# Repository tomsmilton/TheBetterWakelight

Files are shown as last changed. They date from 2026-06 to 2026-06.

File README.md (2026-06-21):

# TheBetterWakelight

Two independent takes on the same idea: an **ESP32-based DMX sunrise
controller for the Neewer PL60C**. The ESP32 plugs into the lamp's 5-pin
DMX port and ramps it from black to full daylight before your alarm,
configured from a phone-friendly web portal on your home Wi-Fi.

```
phone ──WiFi──▶ ESP32 ──DMX-512──▶ Neewer PL60C
        http://wakelight.local/
```

Each version is fully self-contained in its own folder — separate firmware,
docs and build setup. Pick whichever you want to build.

## [`v1-dmx-wakelight/`](v1-dmx-wakelight/) — the original build

The first working version. ESP-IDF / PlatformIO firmware that drives the
PL60C over DMX-512 on a configurable, **waypoint-based** sunrise ramp, with a
mobile web UI for schedule setup and real-time control. Mixes interpolated
brightness/colour-temperature waypoints with the PL60C's 17 named special
effects. Includes wiring schematics and helper scripts.

→ [Read the v1 README](v1-dmx-wakelight/README.md)

## [`v2-better-wakelight/`](v2-better-wakelight/) — the better wakelight

The refined product. A purpose-built **custom PCB** (Neutrik 5-pin XLR,
USB-C power, CH340C one-click flashing, THVD1410 RS-485 output stage) plus
firmware and a Wi-Fi setup portal. Ships hardware deliverables — KiCad
project, gerbers, schematics and JLCPCB order files (BOM + pick-and-place).

| Custom PCB — XLR variant (top) | Bottom |
|:---:|:---:|
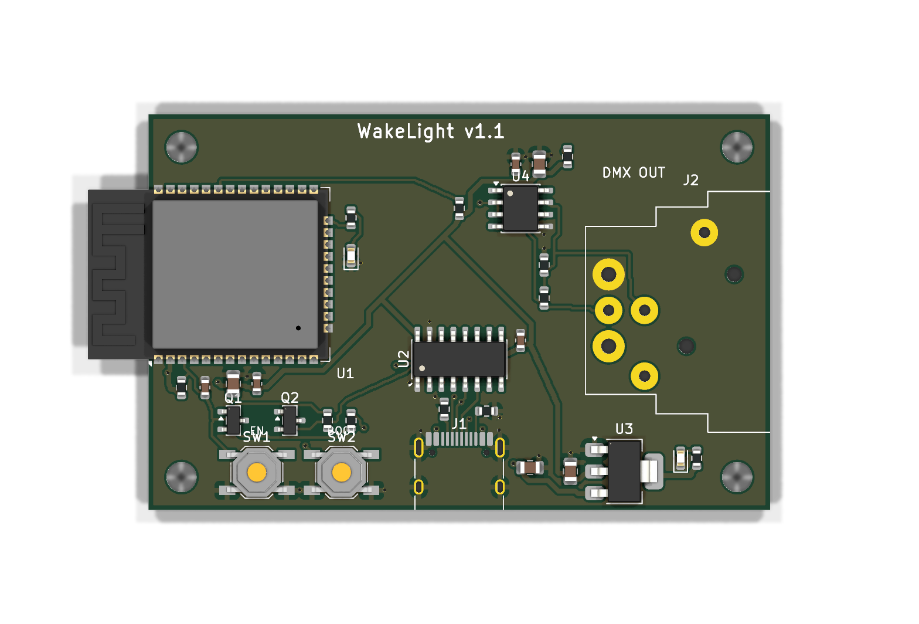
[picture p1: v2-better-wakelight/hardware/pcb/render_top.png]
v2 custom PCB — top
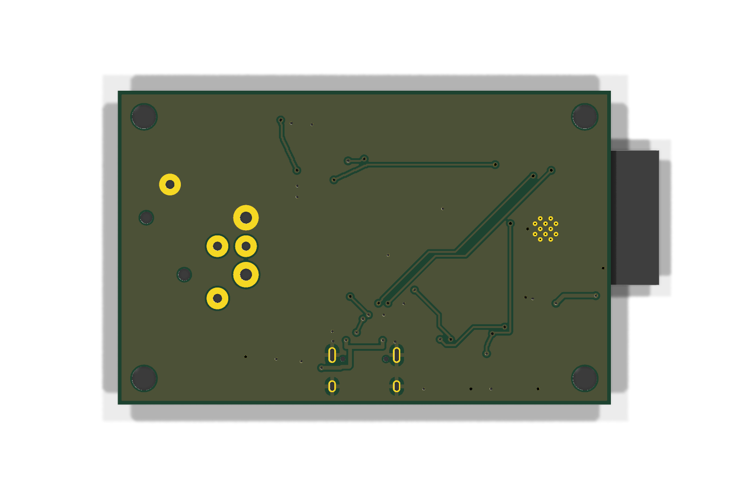
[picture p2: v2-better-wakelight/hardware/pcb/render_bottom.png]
v2 custom PCB — bottom
|  |  |

→ [Read the v2 README](v2-better-wakelight/README.md) ·
[original project brief](v2-better-wakelight/BRIEF.md)

---

Build artifacts (PlatformIO/ESP-IDF output, KiCad caches, generated meshes,
Wi-Fi secrets) are gitignored per-folder.

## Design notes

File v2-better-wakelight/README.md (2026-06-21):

# The Better WakeLight (V2)

A small ESP32 board that plugs into a **Neewer PL60C** LED panel's 5-pin DMX‑IN
and ramps it from black to full daylight before your alarm — a sunrise lamp you
configure from a phone-friendly web page on your home Wi‑Fi.

> [!WARNING]
> **This firmware is rough bring‑up firmware, not a polished release.**
> It works — the DMX output stage is fixed and bench‑tested — but it has not
> been refined or cleaned up. A nicer, **prettier firmware is likely coming in
> July 2026**. If you want the tidy version, check back then. What's here is
> enough to build the board and make the lamp do a sunrise today.

**The custom PCB — XLR variant (v1.1), board-mount Neutrik 5-pin XLR:**

| Top | Bottom |
|:---:|:---:|
| Custom PCB v1.1 — top | Custom PCB v1.1 — bottom |

---

## Where everything is

| You want… | Go to |
|---|---|
| **Order the PCB** (JLCPCB) | [`hardware/pcb/`](hardware/pcb/) — see [Order the board](#order-the-board-jlcpcb) |
| **Flash the firmware** | [`firmware/`](firmware/) — see [Flash it](#flash-it-when-the-board-arrives) |
| **Parts list** (LCSC numbers) | [`orders/lcsc-parts.md`](orders/lcsc-parts.md) |
| **How the lamp's DMX works** | [`docs/dmx-profile.md`](docs/dmx-profile.md) |
| **Why the circuit is built this way** | [`docs/rs485-design-notes.md`](docs/rs485-design-notes.md) |
| **Schematic & wiring diagrams** | [`docs/schematic-diagram.svg`](docs/schematic-diagram.svg), [`docs/wiring-diagram.svg`](docs/wiring-diagram.svg) |
| **Edit/regenerate the board** | [`hardware/pcb/`](hardware/pcb/) — KiCad `wakelight.kicad_pcb` + `generate_board.py` / `route_board.py` |

---

## Order the board (JLCPCB)

The custom PCB is a 2‑layer board, 66 × 42 mm, with a board‑mount Neutrik NC5FAH
female 5‑pin XLR on the edge. Everything JLCPCB needs is already exported in
[`hardware/pcb/`](hardware/pcb/):

| File | What it is | Upload to JLC as |
|---|---|---|
| [`hardware/pcb/wakelight_gerbers.zip`](hardware/pcb/wakelight_gerbers.zip) | The board (copper, mask, silk, drills) | **Gerbers** |
| [`hardware/pcb/jlcpcb_bom.csv`](hardware/pcb/jlcpcb_bom.csv) | Bill of materials (LCSC part numbers) | **BOM** |
| [`hardware/pcb/jlcpcb_cpl.csv`](hardware/pcb/jlcpcb_cpl.csv) | Part positions / rotations | **CPL (Pick‑and‑Place)** |

**Steps**

1. Go to [jlcpcb.com](https://jlcpcb.com) → **Add gerber file** → upload
   [`wakelight_gerbers.zip`](hardware/pcb/wakelight_gerbers.zip).
2. Turn on **PCB Assembly**. When prompted, upload
   [`jlcpcb_bom.csv`](hardware/pcb/jlcpcb_bom.csv) (BOM) and
   [`jlcpcb_cpl.csv`](hardware/pcb/jlcpcb_cpl.csv) (CPL / Pick‑and‑Place).
3. Check the placement preview against
   [`render_top.png`](hardware/pcb/render_top.png) /
   [`render_bottom.png`](hardware/pcb/render_bottom.png), confirm parts, and order.

**Good to know**

- The **XLR connector (J2) is hand‑soldered** (through‑hole) — it is *not* in the
  assembly BOM. Order it separately (the part is listed in
  [`orders/lcsc-parts.md`](orders/lcsc-parts.md)).
- The 120 Ω termination resistor (R11) is intentionally **not populated**; the
  lamp terminates the bus.

---

## Flash it when the board arrives

The firmware is a [PlatformIO](https://platformio.org) project in
[`firmware/`](firmware/). Plug the board into your computer over USB‑C, then pick
one of these.

### Easiest — let Claude Code do it

Open a terminal **inside the `firmware/` folder** and run:

```
claude
```

Then tell it:

> *"Flash this firmware to my ESP32 over USB and help me bring it up."*

It will build, upload, and walk you through Wi‑Fi and lamp setup. (This board was
literally brought up this way.)

### Manual — PlatformIO

If you'd rather drive it yourself, install
[PlatformIO](https://platformio.org/install) (the CLI, or the VS Code extension),
then from the `firmware/` folder:

```
pio run -t upload        # build the production firmware and flash it
pio device monitor       # optional: watch the serial log @ 115200 baud
```

There's also a no‑Wi‑Fi self‑check that proves the DMX output works on the bench:

```
pio run -e selfcheck -t upload     # then watch serial; re-flash the default to restore production
```

### Set up the lamp

On the PL60C: **DMX mode ON, address 001** (long‑press MENU → DMX → ON, then
ADDR → 001). Plug the board's XLR into the panel's **DMX‑IN**.

### First boot / Wi‑Fi

The board opens a hotspot **`WakeLight-Setup`** (password `sunrise123`). Join it,
enter your home Wi‑Fi, then open **http://wakelight.local** to set per‑day alarms,
run the 2‑minute sunrise demo, and control brightness / colour temperature.

---

## How it works (short version)

- **Output stage:** ESP32 (GPIO17 TX) → THVD1410 RS‑485 driver → female 5‑pin XLR.
  It's transmit‑only, so the driver enable (GPIO21) is simply held HIGH in
  firmware. Diagrams in [`docs/`](docs/).
- **Sunrise:** a two‑phase dawn ramp that reaches 100 % at your alarm time, then
  holds for a configurable time and switches off.
- **Details:** [`docs/rs485-design-notes.md`](docs/rs485-design-notes.md) (circuit)
  and [`docs/dmx-profile.md`](docs/dmx-profile.md) (the PL60C's DMX channels).

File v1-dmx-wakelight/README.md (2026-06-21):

# Wakelight

A DMX-controlled wake-up light. An ESP32 drives a Neewer PL60C
(or any single-fixture DMX-512 channel) on a configurable sunrise ramp
each morning, with a small mobile-friendly web UI for setup and
real-time control.

```
phone ──WiFi──▶ ESP32 ──DMX-512──▶ PL60C
        http://wakelight.local/
```

## What it does

<p align="center">
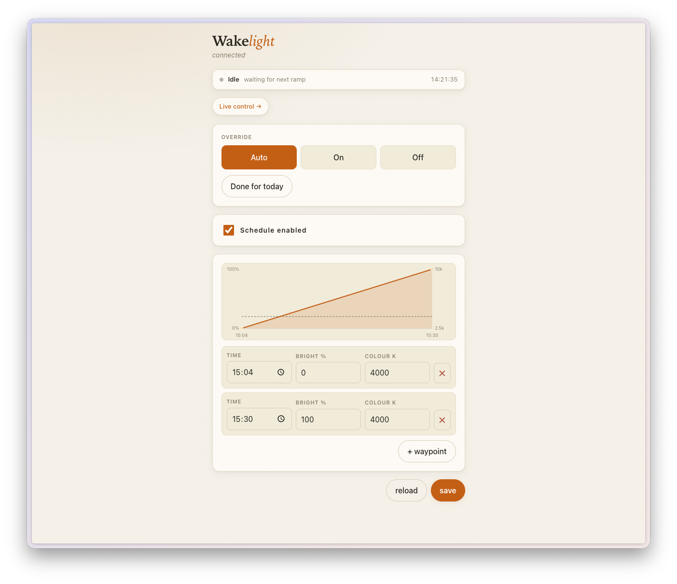
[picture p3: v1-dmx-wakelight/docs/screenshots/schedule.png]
Schedule page
  
  &nbsp;&nbsp;
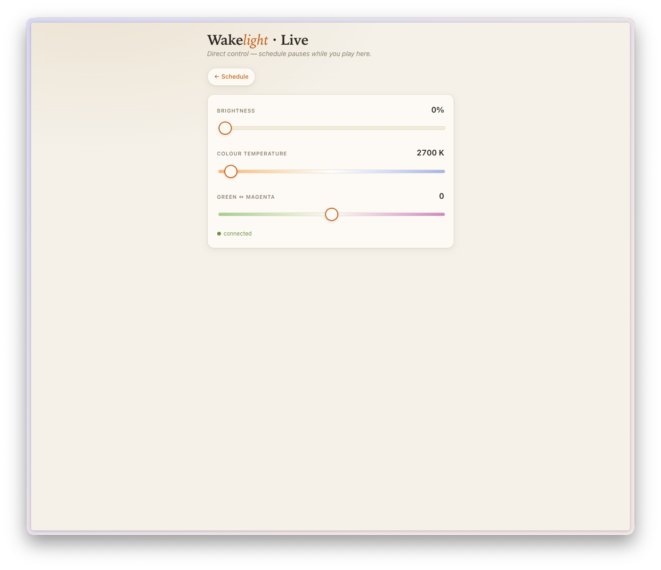
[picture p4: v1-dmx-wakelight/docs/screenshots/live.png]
Live control page
  
</p>

### Schedule (`/`)

A ramp is defined by an ordered list of **waypoints**. Two flavours,
mixable in a single schedule:

- **Light** waypoints (💡): time of day, brightness %, colour temperature
  in kelvin. Adjacent Light waypoints linearly interpolate (in DMX-byte
  space, so fades are smoother than 1%-step quantisation would give you).
- **Effect** waypoints (✨): time of day, brightness %, plus one of the
  PL60C's 17 named special effects (Lightning, Cop car, Candlelight,
  Fireworks, …) with effect-specific parameters. Effect waypoints don't
  interpolate — they fire at their time and hold the effect until the
  next waypoint.

Mixed segments (Light → Effect, Effect → anything) hold the start
waypoint's state until the next waypoint's time. Past the last waypoint,
the lamp **holds at those values** until either:

- you press *Done for today* (terminal — see below), or
- the calendar rolls past midnight, or
- you save a new schedule whose first waypoint is in the future.

The schedule is stored in NVS so it survives power cycles.

The *link times* toggle (🔗 above the waypoint list) shifts every
other waypoint by the same delta when you change one — handy for
nudging the whole ramp forward or back without re-entering each row.
The *default ramp* button reseeds a five-point morning curve as a
starting point. *+ light* / *+ effect* add a new waypoint of either
type.

> **Effect waypoints require Mode 3 on the lamp.** The PL60C must be
> physically set to Mode 3 (FX, 9-channel) on its menu for FX bytes to
> apply — Mode 1 (CCT, 4-channel) ignores the higher slots so FX
> waypoints silently produce no light. Light waypoints work in either
> mode.

### Override buttons

Three pill buttons sit above the schedule:

- **Auto** — follow the schedule (default)
- **On** — force 100 % at 4000 K
- **Off** — force the lamp dark

Override is in-memory only; a power cycle resets to Auto.

### Done for today

A one-shot button below the override row. Pressing it suppresses the
schedule for the rest of the local day. **There is no resume.** It
persists to NVS, so a reboot before midnight still keeps the lamp off.
At local midnight the date comparison auto-clears it for tomorrow's
ramp.

If you save a new schedule whose first waypoint is later than the
current time, the dismiss is automatically dropped — assumed-intent
that the new ramp should fire.

### Live control (`/live`)

A separate page with three sliders driven over a WebSocket:

- **Brightness** 0–100 %
- **Colour temperature** 2500–10000 K (warm-to-cool gradient track)
- **Green ↔ Magenta** −100 to +100 (G/M tint, 0 = neutral)

When you move a slider the firmware switches into a `MANUAL` mode and
pushes the new DMX frame immediately (~30 ms throttle on the wire).
**Closing the tab does not revert the lamp** — manual values stay until
you explicitly hit Auto/On/Off on the schedule page. Re-opening the
Live page seeds the sliders from the lamp's current effective state.

### Multiple lamps

Each device derives an mDNS hostname from its friendly name (e.g.
"Bedroom" → `bedroom.local`). On boot it probes the LAN; if the slug
is already taken by another wakelight it falls back to `slug-2`,
`slug-3`, …, and ultimately to a MAC-derived `wakelight-XXXX` that's
guaranteed unique.

The first lamp to come up also claims `wakelight.local` as a delegate
hostname. Hitting `http://wakelight.local/` from anywhere on the LAN
serves a picker that lists every lamp it can see and links through
to each one's slug URL. Discovery is via a `_wakelight._tcp` mDNS
service whose TXT records carry `name` and `slug`.

Rename a lamp from the *This lamp* card on the schedule page. The
firmware probes the new slug for clashes and returns 409 if another
wakelight is already using it. Names persist in NVS.

### Status pill

Top of the schedule page, polled every 5 s:

| State | Meaning |
|---|---|
| Ramping (pulsing) | Interpolating between two waypoints |
| Holding | Past the last waypoint, lamp held |
| Manual | Live sliders are driving |
| On / Off | Override is active |
| Dismissed | Done for today, schedule paused |
| Idle | Before today's first waypoint |
| No time | SNTP hasn't synced yet |

### Graph

Read-only SVG preview of the ramp on the schedule page. Brightness as
a filled curve (terracotta), CCT as a dashed line, dot at each
waypoint coloured by its CCT. Driven entirely by the waypoint table —
not editable from the graph.

## Architecture

```
┌──────────────┐                          ┌──────────────┐
│ index.html   │  GET  /api/schedule      │  schedule    │  ◀─NVS
│ live.html    │  PUT  /api/schedule      │  (waypoints) │
│ picker.html  │  GET  /api/status (5s)   ├──────────────┤
│              │  POST /api/override      │  override    │
│ (gzipped     │  POST /api/dismiss       │  (atomic)    │
│  & embedded  │  GET  /api/device        ├──────────────┤
│  in flash)   │  PUT  /api/device        │  dismiss     │  ◀─NVS
│              │  GET  /api/peers         │  (atomic)    │
│              │  WS   /ws/live           ├──────────────┤
└──────────────┘                          │  device_id   │  ◀─NVS
                                          │  (name+slug) │
                                          └──────────────┘
                                                  │
                                                  ▼ 1 Hz
                                          ┌──────────────┐
                                          │  ramp_task   │
                                          │  resolves to │
                                          │  (b, k, gm)  │
                                          └──────────────┘
                                                  │
                                                  ▼
                                          ┌──────────────┐  30 ms
                                          │  dmx_tx task │ ────▶ DMX wire
                                          └──────────────┘
```

The ramp task is the single decision point. Every second it reads the
override mode, the dismiss flag and the schedule, and resolves them to
a `(brightness_byte, cct_k, gm_byte)` triple that the DMX sender task
keeps pumping at 33 Hz.

See `docs/audit` (or grep for `ramp_task` in [src/main.c](src/main.c))
for a full state machine.

## Hardware

- **MCU**: ESP32 dev board (any with at least 1 MB app partition)
- **DMX driver**: an RS-485 transceiver wired to GPIO 17 (TX), GPIO 16
  (RX), GPIO 4 (DE/RE)
- **Fixture**: Neewer PL60C, address **`1`**. Use **Mode 1 (CCT,
  4-channel)** for plain ramps or **Mode 3 (FX, 9-channel)** if you
  also want effect waypoints — Mode 3 still serves CCT correctly via
  the same slot ordering. Mode/address selection lives in
  [src/dmx_out.c](src/dmx_out.c) (`FIXTURE_ADDR`, `FX_MODE_BYTE`).
  Other 4-channel CCT fixtures with the same slot order (mode /
  brightness / CCT / G-M) should work unchanged for Light-only
  schedules.

## Setup

### 1. Toolchain

[PlatformIO](https://platformio.org/) does the heavy lifting; install
it however you like (VS Code extension, `brew install platformio`,
`pip install platformio`, …).

### 2. WiFi credentials

```bash
cp src/wifi_secrets.h.example src/wifi_secrets.h
# edit src/wifi_secrets.h with your SSID + password
```

`src/wifi_secrets.h` is gitignored.

### 3. Build & flash

```bash
pio run -e wakelight -t upload
```

First boot the ESP joins WiFi, syncs SNTP from `pool.ntp.org` (London
TZ with auto DST is hard-coded — change `setenv("TZ", ...)` in
[src/wifi_sntp.c](src/wifi_sntp.c) if you're elsewhere), advertises
itself on mDNS at `wakelight-<MAC4>.local` (or your chosen slug, see
[Multiple lamps](#multiple-lamps)), opportunistically claims
`wakelight.local` as a delegate, and the schedule loads from NVS (or
seeds with a default morning ramp on a fresh device).

### 4. Open the UI

On a phone connected to the same WiFi:

- `http://wakelight.local/` — picker that lists every lamp on the
  network and links through to its schedule page
- `http://<slug>.local/` — schedule page for that lamp directly
- `http://<slug>.local/live` — live sliders

If mDNS doesn't resolve on your network, the IP shows up in the serial
log on boot — use that instead.

### 5. Logs

A small Python helper tails serial in the background and writes to
`logs/serial.log`:

```bash
python3 scripts/serial_tail.py
```

Default log level is **WARN** (chosen for size — see *Footprint*
below). Bump `CONFIG_LOG_DEFAULT_LEVEL_INFO=y` in
[sdkconfig.wakelight](sdkconfig.wakelight) for verbose boot output.

## Footprint

The firmware is intentionally lean: ~750 KB on a 1 MB app partition
(72 % used). Choices that matter:

- `-Os` with silent assertions
- newlib-nano formatter (no float `printf`)
- IPv6 + mbedtls cert bundle disabled
- HTML embeds gzip-compressed and served with `Content-Encoding: gzip`
- mDNS, RDM (in `esp_dmx`) kept on; both are candidates if you ever
  need more headroom

DMX timing requires `CONFIG_DMX_ISR_IN_IRAM=1` (already set as a
build flag in [platformio.ini](platformio.ini)) — without it, WiFi's
flash-cache disables corrupt DMX frames around association.

## Repository layout

```
src/
  main.c            boot + 1 Hz ramp task
  dmx_out.{c,h}     DMX driver wrapper, atomic packed setpoint
  schedule.{c,h}    waypoint model, NVS persistence, interpolation
  override.{c,h}    auto/on/off/manual mode + manual values
  dismiss.{c,h}     "done for today", date-anchored, NVS-persisted
  device_id.{c,h}   friendly name → slug, MAC-derived fallback, NVS
  wifi_sntp.{c,h}   STA join + London TZ + SNTP
  http_ui.{c,h}     HTTP server, /api endpoints, WebSocket, mDNS
  index.html        schedule page (gzipped at build time)
  live.html         live slider page (gzipped at build time)
  picker.html       served at wakelight.local; lists discovered peers
  wifi_secrets.h.example   copy → wifi_secrets.h, gitignored
scripts/
  gen_index_html.py prebuild: gzip + embed HTML into C
  serial_tail.py    serial logger
sdkconfig.wakelight pruned IDF config
platformio.ini      build environments
info/               vendor docs (PL60C DMX command table)
```

## Common adjustments

| Want | Change |
|---|---|
| Different timezone | `setenv("TZ", ...)` in [src/wifi_sntp.c](src/wifi_sntp.c) |
| Different fixture address | `FIXTURE_ADDR` in [src/dmx_out.c](src/dmx_out.c) |
| Different DMX pins | `TX_PIN`, `RX_PIN`, `EN_PIN` in [src/dmx_out.c](src/dmx_out.c) |
| Different ON-button defaults | `OVERRIDE_ON_BYTE`, `OVERRIDE_ON_CCT` in [src/main.c](src/main.c) |
| More waypoints per schedule | `SCHEDULE_MAX_POINTS` in [src/schedule.h](src/schedule.h) |
| Faster ramp recompute | `period` in `ramp_task` ([src/main.c](src/main.c)) — note the 8-bit DMX byte caps perceptible smoothness regardless |

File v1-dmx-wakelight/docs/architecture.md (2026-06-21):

## Firmware architecture

```mermaid
flowchart TB
  subgraph UI["User Interface (Browser)"]
    IDX["Schedule Page<br/>index.html"]
    LIV["Live Page<br/>live.html"]
  end

  subgraph FW["ESP32 Firmware"]
    direction TB

    subgraph NET["wifi_sntp.c"]
      WIFI["STA join + SNTP<br/>London TZ, WIFI_PS_NONE"]
    end

    subgraph HTTP["http_ui.c"]
      HSRV["HTTP server + mDNS<br/>GET / , GET /live (gzipped HTML)<br/>GET/PUT /api/schedule<br/>GET /api/status<br/>POST /api/override<br/>POST /api/dismiss"]
      WS["WebSocket /ws/live<br/>recv {b, k, gm}"]
    end

    subgraph STATE["State"]
      SCHED["schedule.c<br/>schedule_t { waypoint_t[10] }<br/>CCT or FX per point (tagged union)<br/>mutex-guarded g_cur"]
      OVR["override.c<br/>override_mode_t + manual vals<br/>packed in atomic uint32 (RAM only)"]
      DISM["dismiss.c<br/>g_dismissed_ord (atomic int)<br/>YYYY*512 + MM*32 + DD"]
    end

    RAMP["main.c — ramp_task<br/>1 Hz, prio 4<br/>reads override → dismiss → schedule<br/>resolves CCT (b, cct_k, gm)<br/>or FX (b, effect, p[6])"]
    DMXC["dmx_out.c<br/>portMUX-guarded g_state<br/>CCT or FX setpoint paths<br/>cct_to_byte(2500..10000 → 0..255)"]
    SEND["sender_task<br/>33 Hz (30 ms), prio 10, core 1<br/>writes slots [1..4] (CCT) or<br/>[1..9] (FX) of DMX frame"]
  end

  NVS[("NVS<br/>ns=wakelight<br/>keys: schedule, dism_ord")]

  subgraph HW["Physical"]
    RS485["RS-485 transceiver<br/>TX=GPIO17 · RX=GPIO16 · DE/RE=GPIO4"]
    LAMP["Neewer PL60C @ DMX addr 1<br/>Mode 1 CCT<br/>slots: mode · bright · CCT · G/M"]
  end

  IDX -- "REST JSON" --> HSRV
  LIV -- "GET /live" --> HSRV
  LIV -- "JSON over WS" --> WS

  HSRV -- "schedule_get / schedule_save" --> SCHED
  HSRV -- "override_set" --> OVR
  HSRV -- "dismiss_for_today" --> DISM
  HSRV -- "override_get + schedule_eval<br/>(mirrors ramp for /api/status)" --> RAMP

  WS -- "override_set_manual()" --> OVR
  WS -- "dmx_out_set() (immediate)" --> DMXC

  SCHED <--> NVS
  DISM  <--> NVS

  WIFI --> HSRV
  WIFI --> WS

  SCHED -. "schedule_get" .-> RAMP
  OVR   -. "override_get / override_get_manual" .-> RAMP
  DISM  -. "dismiss_is_active" .-> RAMP
  SCHED -. "schedule_save drops dismiss<br/>if first waypoint is future" .-> DISM

  RAMP -- "dmx_out_set(byte, cct_k, gm)" --> DMXC
  DMXC --> SEND
  SEND -- "dmx_write + dmx_send_num<br/>via esp_dmx on UART1" --> RS485
  RS485 -- "DMX-512" --> LAMP
```

### Notes grounded in the code

- **Single decision point.** [`ramp_task`](../src/main.c) runs at 1 Hz and is the only
  path that translates override + dismiss + schedule into a DMX set point
  under `AUTO`. `MANUAL` and `ON`/`OFF` short-circuit earlier in the same
  task.
- **WS bypass for latency.** [`live_ws_h`](../src/http_ui.c) calls
  `dmx_out_set()` directly after `override_set_manual()` so slider moves
  don’t wait for the 1 Hz tick. The next `ramp_task` tick then repaints
  the same values from the atomic override state.
- **Atomic + spinlock for setpoints.** `override.c` packs mode + manual
  (brightness_pct, cct_k, gm_byte) into one `_Atomic uint32_t`. `dmx_out.c`
  uses a `portMUX_TYPE` spinlock around its setpoint struct because the FX
  path carries 9 bytes and no longer fits in a single 32-bit atomic;
  critical sections are read-snapshot/write-only and ~tens of ns.
- **Schedule uses a mutex.** `schedule_t` is ~120 bytes so it’s copied
  under `g_lock` in [`schedule_get`](../src/schedule.c) / `schedule_save`.
- **NVS is only for schedule + dismiss.** Override is deliberately
  RAM-only — boot returns to `AUTO`.
- **Dismiss auto-clears** inside `schedule_save` when the new schedule’s
  first waypoint is later than the current minute-of-day (treats
  "saved a forward schedule" as intent to fire).
- **DMX pacing.** `sender_task` is pinned to core 1 at priority 10, above
  `ramp_task` (prio 4), so WiFi work on core 0 can’t starve the 30 ms
  frame cadence. `CONFIG_DMX_ISR_IN_IRAM=1` (see `platformio.ini`) keeps
  the ISR resident during flash-cache disables.

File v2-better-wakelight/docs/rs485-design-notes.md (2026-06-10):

# RS-485 / DMX output stage — design decisions

Distilled from research (June 2026). Full sources in research transcript.

## Decisions

| Topic | Decision | Why |
|---|---|---|
| Library | `esp_dmx` v4.1.0, **pinned to `espressif32@6.x`** (Arduino core 2.0.17) | v4.1.0 does not compile on IDF5/core 3.x (PR #223 unmerged). Hardware-UART driven, correct E1.11 break/MAB timing, immune to Wi-Fi jitter. |
| DMX task | Own FreeRTOS task pinned to **core 1**, full 513-slot frame every 25 ms | Wi-Fi/lwIP live on core 0. Web handlers never call `dmx_send()` — they update a shared `Look`. |
| Flash writes | `dmx_driver_disable()`/`enable()` around NVS saves | Flash writes stall cache; DMX ISR is in flash on Arduino builds → corrupted frames. |
| Transceiver | **TI THVD1410DR** (SOIC-8, LCSC C2671345) for the PCB; SP3485/MAX3485-class 3.3 V breakout for the module build | 3.3 V native (no 5 V rail, no level concerns), 500 kbps slew-limited (clean EMI), ±18 kV IEC ESD on bus pins → no external TVS needed. |
| MAX485 (5 V) fallback | Acceptable transmit-only: V_IH(min)=2.0 V so 3.3 V DI is in spec; power it from 5 V, leave RO unconnected (it would swing 5 V) | The common red Amazon breakout works fine for TX-only. |
| Isolation | **None** | One fixture, bedroom, USB wall adapter (already mains-isolated). DMX512-A only *recommends* isolation; Enttec Open DMX class devices are non-isolated. |
| Termination | None fitted at transmitter; 120 Ω DNP footprint across A–B | Bus is terminated once at the far end (the lamp / a terminator plug). Fit only if RDM later. |
| Fail-safe bias | 680 Ω A→3.3 V, 680 Ω B→GND (fitted) | Cheap insurance through reset/boot gaps; matches SparkFun shield practice. |
| DE & /RE | Tied together, GPIO21, plus 10 kΩ pull-up to 3.3 V | Driver enabled through boot; pass GPIO21 as the RTS pin in `dmx_set_pin()`. |

## Pinout

```
ESP32 GPIO17 (UART1 TX) ──► DI
ESP32 GPIO21            ──► DE + /RE (tied, 10k pull-up to 3V3)
RO                      ──  n/c (transmit-only)
A  (D+)                 ──► XLR pin 3
B  (D−)                 ──► XLR pin 2
GND                     ──► XLR pin 1 (signal common)
XLR pins 4,5            ──  n/c (optional data link 2 in the spec)
```

DMX controller output uses a **female** XLR; the lamp's DMX IN is male.

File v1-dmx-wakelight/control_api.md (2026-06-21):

# Wakelight Control API

HTTP + WebSocket control surface for the Wakelight ESP32 firmware. A
single Neewer PL60C CCT lamp on DMX address 1.

This is the full external API — there is nothing else. No auth, no
rate limiting, no SSL. It lives on a LAN and assumes the caller is
trusted.

## Addressing

- **Hostname**: `wakelight.local` (mDNS). If your resolver or network
  can't resolve mDNS, resolve once with
  `dns-sd -G v4 wakelight.local` (macOS) or `avahi-resolve -n
  wakelight.local` (Linux) and use the IP. mDNS can be flaky over
  some Wi-Fi stacks — cache the IP for a long-running agent and
  refresh on any connection error.
- **Port**: 80 (HTTP) and 80 (WebSocket, same port).
- **Example**: `http://wakelight.local/api/status` or
  `http://192.168.0.66/api/status`.

Most examples below show the hostname for readability; substitute an IP
if mDNS is unreliable.

## Time zone

All times exposed and accepted by the firmware are in the **device's
local wall-clock**, not UTC. The device is hardcoded to **Europe/London
with auto DST** (`GMT0BST,M3.5.0/1,M10.5.0`). If you're operating from
another timezone, do the conversion on your side before writing
`minute_of_day` values.

Time is sourced from SNTP (`pool.ntp.org`) at boot. Until SNTP syncs,
`state` is `"no_time"` and you should avoid writing schedules — the
device can't tell what day it is yet.

## Concepts

The lamp's effective output each moment is decided by four inputs,
combined in this priority order:

```
OVERRIDE  >  DISMISS  >  SCHEDULE
```

1. **Override** — one of `auto | on | off | manual`. Defaults to
   `auto` at boot (override is RAM-only). Anything other than `auto`
   short-circuits the schedule.
   - `on`: forces 255 DMX / 4000 K
   - `off`: forces 0 DMX
   - `manual`: driven by sliders over the WebSocket (see below).
     Cannot be set over REST — only a WS message can put the lamp into
     `manual`.
2. **Dismiss** — "done for today" flag, anchored to the local
   date. When active, AUTO mode treats the schedule as if disabled for
   the rest of the day. Persists to flash; auto-clears at local
   midnight.
3. **Schedule** — an ordered list of up to 10 waypoints, each
   `(minute_of_day, brightness %, CCT K)`. Between waypoints the
   firmware linearly interpolates in DMX-byte space for brightness,
   and in kelvin for CCT, once per second. Past the last waypoint,
   the lamp holds at those values until the next day or a new
   schedule. Persists to flash.

### Effective states (`status.state`)

| Value | Meaning |
|---|---|
| `no_time` | SNTP hasn't synced yet; do not write schedules. |
| `on` | Override is ON. |
| `off` | Override is OFF. |
| `manual` | WS slider session is active. |
| `dismissed` | AUTO mode, dismiss flag set for today. |
| `idle` | AUTO mode, before today's first waypoint (or schedule disabled). |
| `ramping` | AUTO mode, interpolating between two waypoints. |
| `holding` | AUTO mode, past the last waypoint, holding final values. |

## Endpoints

All bodies are JSON. No auth headers. Responses always have
`Content-Type: application/json` unless stated.

### `GET /api/status`

Current effective lamp state. Safe to poll at up to ~5 Hz. The UI
polls at 0.2 Hz.

**Response** (200):

```json
{
  "now":            "2026-04-19 18:42:04",
  "mod":            1122,
  "time_valid":     true,
  "active":         false,
  "brightness_pct": 0,
  "cct_k":          2700,
  "override":       "auto",
  "dismissed":      false,
  "gm":             0,
  "state":          "idle",
  "fx":             false
}
```

| Field | Type | Notes |
|---|---|---|
| `now` | string | Local wall-clock, `YYYY-MM-DD HH:MM:SS`. |
| `mod` | int | Minute-of-day in local time (`0..1439`). |
| `time_valid` | bool | False until SNTP syncs. |
| `active` | bool | True if lamp is emitting light (includes MANUAL). |
| `brightness_pct` | int | Effective brightness `0..100`. |
| `cct_k` | int | Effective colour temperature in kelvin. Stale when `fx` is true. |
| `override` | string | One of `auto | on | off | manual`. |
| `dismissed` | bool | Today's ramp suppressed. |
| `gm` | int | Green/magenta tint, `-100..+100`. 0 = neutral. |
| `state` | string | See "Effective states" table above. |
| `fx` | bool | True if the lamp is currently driven by an FX waypoint. |
| `fx_id` | string | Present only when `fx` is true. The effect id (see waypoint table). |

### `GET /api/schedule`

Return the persisted schedule.

**Response** (200):

```json
{
  "enabled": true,
  "points": [
    {"m": 390, "b": 0,   "k": 2500},
    {"m": 410, "b": 30,  "k": 3000},
    {"m": 420, "b": 100, "k": 5000},
    {"m": 480, "b": 80,  "t": "fx", "fx": "lightning",
     "p": [128, 50, 60, 0, 0, 0]}
  ]
}
```

Two waypoint shapes share the array:

| Field | Type | Applies to | Notes |
|---|---|---|---|
| `m` | int | both | `minute_of_day` `0..1439` (local time). |
| `b` | int | both | Brightness % `0..100`. |
| `t` | string | optional | `"cct"` (default if absent) or `"fx"`. |
| `k` | int | CCT only | CCT in kelvin `2500..10000`. |
| `fx` | string | FX only | Effect id (see below). |
| `p` | int[6] | FX only | Raw bytes for fixture channels n+3..n+8. Each `0..255`; clamped. Trailing unused bytes are ignored by the lamp. |

**FX waypoints** trigger one of the lamp's Mode-3 special effects. They do not
interpolate — between an FX waypoint and its successor the lamp holds the
effect; between a CCT and an FX waypoint, the CCT side holds until the FX
fires. CCT→CCT segments still ramp linearly per second.

The lamp **must be physically set to Mode 3** (FX, 9-channel) for FX bytes
to apply. Mode 1 (CCT, 4-channel) ignores the higher slots, so FX waypoints
silently produce no light.

Effect ids (use the string in the `fx` field):

| `fx` | Name | `p` slots used |
|---|---|---|
| `lightning` | Lightning | CCT, Rate, Stop/Start |
| `paparazzi` | Paparazzi | CCT, G/M, Pace, Stop/Start |
| `defective_bulb` | Defective bulb | CCT, G/M, Pace, Stop/Start |
| `explosion` | Explosion | CCT, G/M, Pace, Ember, Stop/Start |
| `welding` | Welding | Brightness, CCT, G/M, Pace, Stop/Start |
| `cct_flash` | CCT flash | CCT, G/M, Pace, Stop/Start |
| `hue_flash` | Hue flash | Hue, Sat, Pace, Stop/Start |
| `cct_pulse` | CCT pulse | CCT, G/M, Pace, Stop/Start |
| `hue_pulse` | Hue pulse | Hue, Sat, Pace, Stop/Start |
| `cop_car` | Cop car | Colours, Pace, Stop/Start |
| `candlelight` | Candlelight | Brightness, CCT, G/M, Pace, Ember, Stop/Start |
| `hue_loop` | Hue loop | Hue 1, Hue 2, Pace, Stop/Start |
| `cct_loop` | CCT loop | CCT 1, CCT 2, Pace, Stop/Start |
| `int_loop` | Intensity loop | Picking, Brightness, CCT/Hue, Rate, Stop/Start |
| `tv_screen` | TV screen | Brightness, CCT, G/M, Pace, Stop/Start |
| `fireworks` | Fireworks | Mode, Rate, Ember, Stop/Start |
| `party` | Party | Mode, Rate, Stop/Start |

The `p` array is always 6 elements; positions past the effect's slot count
are written but ignored by the fixture. See the PL60C manual
(`info/command table.pdf`) for the byte → human-unit mapping per slot
(e.g. CCT `0..255` → `2500..10000 K`, Pace `0..100` in 10-byte steps → 1..10).

### `PUT /api/schedule`

Replace the schedule. The firmware clamps every field to valid range,
sorts points by `m`, and persists to flash.

**Side effect**: if the new schedule is enabled, has at least one
point, and the first point's `m` is strictly greater than `now.mod`,
the dismiss flag is cleared (on the reasoning that saving a
forward-looking schedule is the user's signal they want it to fire).

**Request** (body <= 2048 bytes):

```json
{
  "enabled": true,
  "points": [
    {"m": 390, "b": 0, "k": 2500},
    {"m": 420, "b": 100, "k": 5000}
  ]
}
```

**Response** (200): the schedule as it was actually stored (post-clamp
and post-sort — the caller should treat this as the source of truth,
not the request body).

**Errors**:

| Code | Cause |
|---|---|
| 400 `body too big` | Body exceeded 2048 bytes. |
| 400 `invalid json` | Couldn't parse JSON, or `points` missing/not-array, or a `m`/`b`/`k` entry was non-numeric. |
| 500 | NVS write failed (rare; out-of-space or corrupt partition). |

**Notes**:
- Up to 10 points. Extras are silently truncated.
- Empty `points` array with `enabled: true` is legal but leaves AUTO
  in `idle` forever.
- `enabled: false` keeps the stored points but stops the ramp firing.

### `POST /api/override`

Set the override mode. Override is **RAM-only** — boot resets to
`auto`.

**Request**:

```json
{ "mode": "on" }
```

`mode` must be the literal string `"on"`, `"off"`, or `"auto"`. Any
other value (including `"manual"`, misspellings, or a missing/non-string
field) is silently coerced to `"auto"`. The response always reflects
the state actually applied — use that to detect coercion.

**Response** (200):

```json
{ "mode": "on" }
```

**Semantics**:
- `on` → 255 DMX byte (100 %), 4000 K, neutral tint.
- `off` → 0 DMX byte.
- `auto` → return to schedule + dismiss evaluation.
- Switching override does not touch the schedule or dismiss flag.
- There is no REST route to enter `manual`. Send a WS message instead.

### `POST /api/dismiss`

Mark today as dismissed. Terminal for the local date — there is **no
undo endpoint**. The flag auto-clears at local midnight, or when a
forward-looking schedule is written via `PUT /api/schedule`.

**Request**: no body required. If a body is sent it is ignored.

**Response** (200):

```json
{ "active": true }
```

## WebSocket

### `/ws/live`

Opens a persistent socket for live slider control. Dropping the socket
does **not** revert the lamp — once in `manual`, the lamp stays there
until an explicit `POST /api/override` with `"auto"` / `"on"` / `"off"`.

- **Subprotocol**: plain text JSON frames. No subprotocol header.
- **Max connections**: 4. Extra opens are accepted but older ones may
  get evicted on socket close.
- **Opening does nothing.** The mode does not flip to `manual` until the
  first valid slider frame arrives — so short-lived probing (e.g. a
  reconnect) won't steal from AUTO.

### Frame format (client → server)

Each frame is a single JSON object:

```json
{ "b": 45, "k": 3200, "gm": 0 }
```

| Field | Type | Range | Notes |
|---|---|---|---|
| `b` | int | 0..100 | Brightness %. Required. |
| `k` | int | 2500..10000 | CCT in kelvin. Required. |
| `gm` | int | -100..+100 | Green/magenta tint. Optional; defaults to 0 (neutral). Clamped. |

On each valid frame the firmware:
1. Sets override mode to `manual`.
2. Stores (b, k, gm) as the manual setpoint (atomic).
3. Pushes an updated DMX frame within ~30 ms.

Frames larger than 128 bytes are dropped. Non-text frames are
ignored. Malformed JSON is silently dropped.

### There is no server → client traffic

The WebSocket is write-only from the client's perspective. To observe
the resulting lamp state, poll `GET /api/status`.

### Suggested pacing

Client-side throttle of ~30 ms between frames is appropriate. The
reference UI coalesces slider movements on a 30 ms timer. Sending
much faster than that just queues up redundant frames.

## Recipes

### "Turn the lamp on to a fixed brightness/colour"

If you want a repeatable preset (e.g. "evening reading"), use the
WebSocket:

```python
import json, websocket
ws = websocket.create_connection("ws://wakelight.local/ws/live")
ws.send(json.dumps({"b": 40, "k": 2700, "gm": 0}))
ws.close()
```

Or if you just need max brightness, use the REST override:

```bash
curl -X POST http://wakelight.local/api/override \
  -H 'Content-Type: application/json' -d '{"mode":"on"}'
```

### "Turn the lamp off"

```bash
curl -X POST http://wakelight.local/api/override \
  -H 'Content-Type: application/json' -d '{"mode":"off"}'
```

This overrides the schedule. To return control to the schedule, send
`{"mode":"auto"}`.

### "Stop overriding, let the schedule run"

```bash
curl -X POST http://wakelight.local/api/override \
  -H 'Content-Type: application/json' -d '{"mode":"auto"}'
```

### "Set tomorrow's sunrise: 06:30 start, 07:00 at 100 % / 5000 K"

```bash
curl -X PUT http://wakelight.local/api/schedule \
  -H 'Content-Type: application/json' \
  -d '{
    "enabled": true,
    "points": [
      {"m": 390, "b": 0,   "k": 2500},
      {"m": 410, "b": 30,  "k": 3000},
      {"m": 420, "b": 100, "k": 5000}
    ]
  }'
```

(`m` = `hour * 60 + minute` local time.)

Three waypoints are typical — start, knee, finish — but any count up
to 10 is fine. The firmware linearly interpolates per second between
them.

### "Skip this morning's ramp"

```bash
curl -X POST http://wakelight.local/api/dismiss
```

Auto-clears at midnight.

### "Check whether the ramp is currently running"

```bash
curl -s http://wakelight.local/api/status | jq .state
```

Look for `ramping`, `holding`, or `idle`. If `no_time`, the clock
isn't synced yet — retry in a few seconds.

### "Smoothly fade from the current state to a new brightness over ~N seconds"

There is no server-side fade primitive for ad-hoc fades. Two options:

1. **Drive it from the client** — open the WebSocket, interpolate
   `b` and `k` locally at ~10 Hz, send each step. Closing the WS
   leaves the lamp at the last sent values.
2. **Use the schedule** — write a short 2-point schedule with `m` set
   to the current minute and the target minute. Simpler, but
   minute-granular start/end. Also: saving a forward-looking schedule
   clears the dismiss flag (mostly harmless for ad-hoc fades).

The WebSocket path is preferred for ad-hoc transitions.

## Limits and gotchas

- **No observable `manual` REST entrypoint.** To enter `manual`, you
  must open the WebSocket and send at least one valid frame.
- **Override is RAM-only.** A device reboot drops `on` / `off` /
  `manual` back to `auto`. Persisting intent is the caller's job.
- **Dismiss is one-shot per day and has no undo endpoint.** If you
  need to cancel a dismiss, writing any forward-looking schedule
  clears it.
- **Schedule writes are destructive.** The API is PUT (replace), not
  PATCH. To modify one point, read the current schedule, mutate the
  list, write it back. Note `PUT` echoes the clamped/sorted result,
  which may differ from the request.
- **Times are all local.** Hardcoded to Europe/London + DST. Adjust on
  the client if operating from elsewhere; there is no runtime way to
  change the TZ.
- **`state == "no_time"` is load-bearing.** During the 10-30 s window
  between boot and SNTP sync, the date is unknown — schedules still
  persist, but `state` stays `no_time` and AUTO produces no output.
  Wait for `time_valid: true` before writing a dismiss or a schedule
  that depends on "today".
- **Max 10 waypoints per schedule.** Extras are silently truncated.
- **PUT body cap 2048 bytes.** Overrun returns 400.
- **Override POST body cap 63 bytes.** Overrun is silently truncated;
  the JSON parser will usually then reject and the mode falls through
  to `auto`.
- **The device only drives one fixture**, on DMX address 1, mode 1
  (CCT). Multi-fixture control is out of scope.
- **The schedule graph persists.** The lamp will execute stored
  schedules on its own every morning regardless of network state — if
  the agent goes offline, yesterday's schedule still fires.

## Quick reference

| Method | Path | Purpose |
|---|---|---|
| GET | `/api/status` | Read current state. |
| GET | `/api/schedule` | Read stored schedule. |
| PUT | `/api/schedule` | Replace stored schedule. |
| POST | `/api/override` | Set override mode (`auto`/`on`/`off`). |
| POST | `/api/dismiss` | Mark today as dismissed. |
| WS | `/ws/live` | Drive `manual` mode in real time. |

| Literal | Value |
|---|---|
| `minute_of_day` range | `0..1439` |
| Brightness range | `0..100` % |
| CCT range | `2500..10000` K |
| GM range | `-100..+100` |
| Max schedule points | 10 |
| Max PUT body | 2048 bytes |
| Max WS frame | 128 bytes |
| Override POST body cap | 63 bytes |

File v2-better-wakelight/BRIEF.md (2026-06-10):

# Original project brief

> I am working on an engineering project that takes a newer PL60C that has a
> wired 5-pin DMX connector on it and turns that into a wake-up lamp. The
> goal, therefore, is to use this port to ramp up the light in the morning.
>
> Now, I can be your hands in the world, but I really want you to act very,
> very autonomously throughout this, really just pursuing what you need to.
> The goal for me is to have some electronics to control this DMX port and to
> ramp up the lamp in the morning. My basic idea is to have an ESP32 and use
> that to somehow control this port. You need to work out the protocol and
> all of this and how to wire it in. Ideally, what I want you to make is
> actual designs for the hardware, for example, a printed circuit board
> design.
>
> You're going to loop and loop and loop and loop and loop until you really
> think you've actually completed this, an actual finished design. At the
> same time, you should be thinking about the firmware that runs on the ESP32
> and presents on my home Wi-Fi a portal that I can log in to. Clarifying
> questions: ask me those questions, and then, once you've done that, you're
> going to go and run as a really great electronic product engineer who's
> making this beautiful MVP product. You're going to give me parts lists,
> you're going to give me made-up PCBs, all sorts, until you get to the point
> where I can just click the buttons to order and I can have a wake lamp that
> lights up just the next morning.

— Tom Milton, 10 June 2026

## Clarifications given

- Lamp: **Neewer PL60C** LED panel
- Build path: **both** — module build for speed + custom PCB as the product
- Region: **UK** sourcing
- Portal: sunrise CCT ramp, per-day schedules, manual control page, NTP with
  automatic DST

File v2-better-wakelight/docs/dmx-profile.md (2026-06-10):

# Neewer PL60C — DMX profile (from the official Neewer channel table)

Source: Neewer "PL60C DMX Channel Table" PDF (doc 4-08-00-002013, 2024-04-24),
fetched from Neewer's support CDN; corroborated by the PL60C user manual and an
ENTTEC support thread. Full citations in the research transcript.

## The fixture

- NEEWER PL60C, 60 W RGBCW panel (R/G/B/Cool-White/Warm-White emitters)
- CCT 2500K–10000K (±100K), G/M −50…+50, CRI≥96
- **DMX-IN: male 5-pin XLR** chassis; DMX-OUT: female 5-pin XLR (for daisy-chain)
- Pinout: 1 = common/ground, 2 = Data−, 3 = Data+, 4/5 = not assigned (standard E1.11)
- No RDM. Address + DMX ON/OFF set in the lamp menu (long-press MODE/MENU)
- **On DMX signal loss the lamp holds the last look** (it does not black out)

## Channel map (n = DMX start address, default 1)

One personality. Channel n always selects the operating mode; n+1 is always
brightness. Reserve 9 channels worst-case.

| n value | Mode |
|---|---|
| 0–31 | CCT |
| 32–63 | HSI |
| 64–95 | FX (18 effects, sub-channel tables) |
| 96–127 | Gel (Rosco/LEE) |
| 128–159 | RGBCW (direct 5-emitter) |
| 160–191 | XY (CIE x/y) |

### CCT mode (what WakeLight uses for the sunrise)

| Ch | Function | Mapping |
|---|---|---|
| n | Mode select | write **16** (constant) |
| n+1 | Brightness | 0–255 = 0–100% |
| n+2 | Colour temperature | 0–255 linear 2500K → 10000K (≈29.4 K/step) |
| n+3 | G/M tint | 0 = −50 (green)… 128 ≈ 0 … 255 = +50 (magenta) |

### HSI mode (manual colour in the portal)

| Ch | Function | Mapping |
|---|---|---|
| n | Mode select | write **48** (constant) |
| n+1 | Intensity | 0–255 = 0–100% |
| n+2 | Hue | 0–255 = 0–360° |
| n+3 | Saturation | 0–255 = 0–100% |

## Lamp setup for WakeLight (one-time)

1. Long-press **MODE/MENU** → set **DMX → ON**
2. Menu → **DMX ADDR → 001** (or set with the SET dial in the DMX screen)
3. Optional: menu → **DIMMING CURVE → Linear** — WakeLight applies its own
   perceptual dawn curve, so a linear fixture curve gives the most predictable
   low-end ramp
4. Plug the WakeLight's female 5-pin XLR into **DMX-IN**

To use the lamp normally again (panel/app/2.4G), set DMX → OFF.

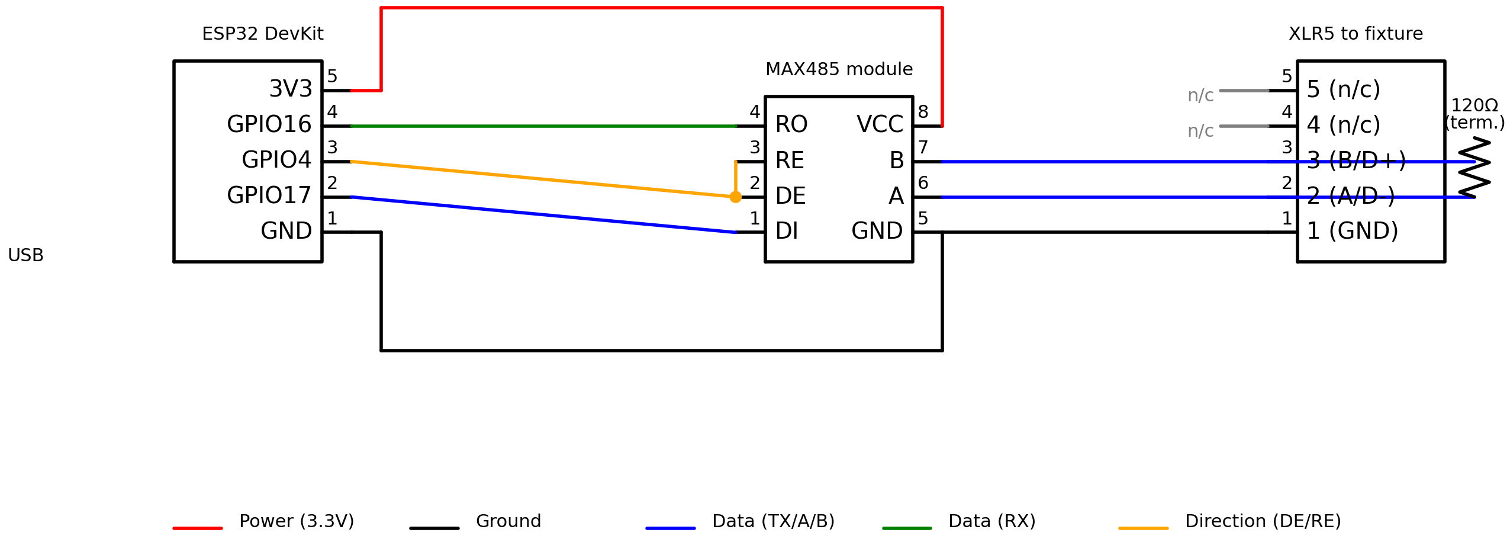
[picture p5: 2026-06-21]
v1-dmx-wakelight/hardware/dmx_schematic.png

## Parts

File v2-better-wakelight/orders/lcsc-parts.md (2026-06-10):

# JLCPCB parts — verified 2026-06-10

Already baked into `hardware/pcb/jlcpcb_bom.csv`. Re-check the matched-parts
screen when uploading; JLC reshuffles Basic/Extended periodically.

| Ref | Part | LCSC # | Library | Note |
|---|---|---|---|---|
| U1 | ESP32-WROOM-32E-N8 | **C701342** | Extended | (C701343 is the 16MB variant — wrong) |
| U2 | CH340C SOP-16 | C84681 | Extended | Listing flagged EOL but 80k stock — fine for this run; CH340K/X for a future rev |
| U3 | AMS1117-3.3 | C6186 | Basic | |
| U4 | THVD1410DR | C2671345 | Extended | RS-485 driver, ±18 kV ESD |
| J1 | USB-C TYPE-C-31-M-12 | C165948 | Extended | |
| J2 | Neutrik NC5FAH 5-pin female XLR (v1.1) | not in BOM | — | **Hand-soldered** (8 THT holes, 6 electrical). Buy: Rapid 20-1840 £3.11 ([rapidonline.com](https://www.rapidonline.com/neutrik-nc5fah-d-5-pin-xlr-female-socket-dmx-20-1840), 400+ stock, free UK ship) or CPC AV11169. Successor **NC5FAH1** has an identical footprint — either fits. LCSC stocks it too (**C368501**, ~$5) if you'd rather have JLC fit it — add it to the BOM/CPL manually and expect a THT-assembly fee. Footprint verified hole-by-hole against Neutrik drawing ST-NC5FAH + DXF. |
| Q1,Q2 | SS8050 | C2150 | Basic | |
| R 0603 | 5.1k C23186 · 10k C25804 · 1k C21190 · 680R C23228 | | Basic | |
| C | 100n C14663 · 1u C15849 · 10u C15850 · 22u C45783 · 4.7u C1779 | | Basic | |
| D1 | Red LED 0603 KT-0603R | C2286 | Basic | |
| D2 | Blue LED 0603 KT-0603B | **C2288** | Extended | (C72041 nearly out of stock) |
| SW1,SW2 | XKB TS-1187A-B-A-B | C318884 | Basic | |
| R11 | 120R termination | — | — | **Intentionally DNP** — fit only if you ever do RDM |

- Both U1 (module) and J2 (THT terminal) are supported on **Economic** assembly;
  JLC auto-adds a small assembly-fixture fee for the module.
- 6 extended parts → ~$18 in feeder fees; per-board parts ≈ $6.6.
- Rotation: U1's KiCad↔JLC library mismatch is **already corrected in the CPL**
  (verified against the placement preview 2026-06-10 — JLC value 0° puts the
  antenna off the left edge). Still re-check the preview after re-upload:
  U1 antenna overhanging LEFT, J1 tongue off the BOTTOM edge, U3 tab toward
  the top edge, D1/D2 pin-1 (cathode) markers on the lower pad of each.
- U2: JLC may substitute their in-stock CH340C listing (e.g. C7464026) for the
  EOL-flagged C84681 — fine, as long as the matched part is CH340**C**, SOP-16.

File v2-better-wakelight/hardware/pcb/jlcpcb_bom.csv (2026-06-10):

Comment | Designator | Footprint | LCSC Part #
10k 0603 | R8,R4,R5,R3 | R_0603_1608Metric | C25804
100nF 0603 | C5,C7,C3 | C_0603_1608Metric | C14663
Blue LED 0603 KT-0603B | D2 | LED_0603_1608Metric | C2288
THVD1410DR | U4 | SOIC-8_3.9x4.9mm_P1.27mm | C2671345
680R 0603 | R10,R9 | R_0603_1608Metric | C23228
1uF 0603 | C6 | C_0603_1608Metric | C15849
USB-C 16P TYPE-C-31-M-12 | J1 | USB_C_Receptacle_HRO_TYPE-C-31-M-12 | C165948
SS8050 | Q1,Q2 | SOT-23 | C2150
Red LED 0603 | D1 | LED_0603_1608Metric | C2286
10uF 0805 | C1 | C_0805_2012Metric | C15850
ESP32-WROOM-32E-N8 | U1 | ESP32-WROOM-32E | C701342
5.1k 0603 | R2,R1 | R_0603_1608Metric | C23186
22uF 0805 | C2,C4 | C_0805_2012Metric | C45783
4.7uF 0805 | C8 | C_0805_2012Metric | C1779
Tact switch TS-1187A | SW1,SW2 | SW_SPST_TL3342 | C318884
AMS1117-3.3 | U3 | SOT-223-3_TabPin2 | C6186
CH340C | U2 | SOIC-16_3.9x9.9mm_P1.27mm | C84681
1k 0603 | R7,R6 | R_0603_1608Metric | C21190

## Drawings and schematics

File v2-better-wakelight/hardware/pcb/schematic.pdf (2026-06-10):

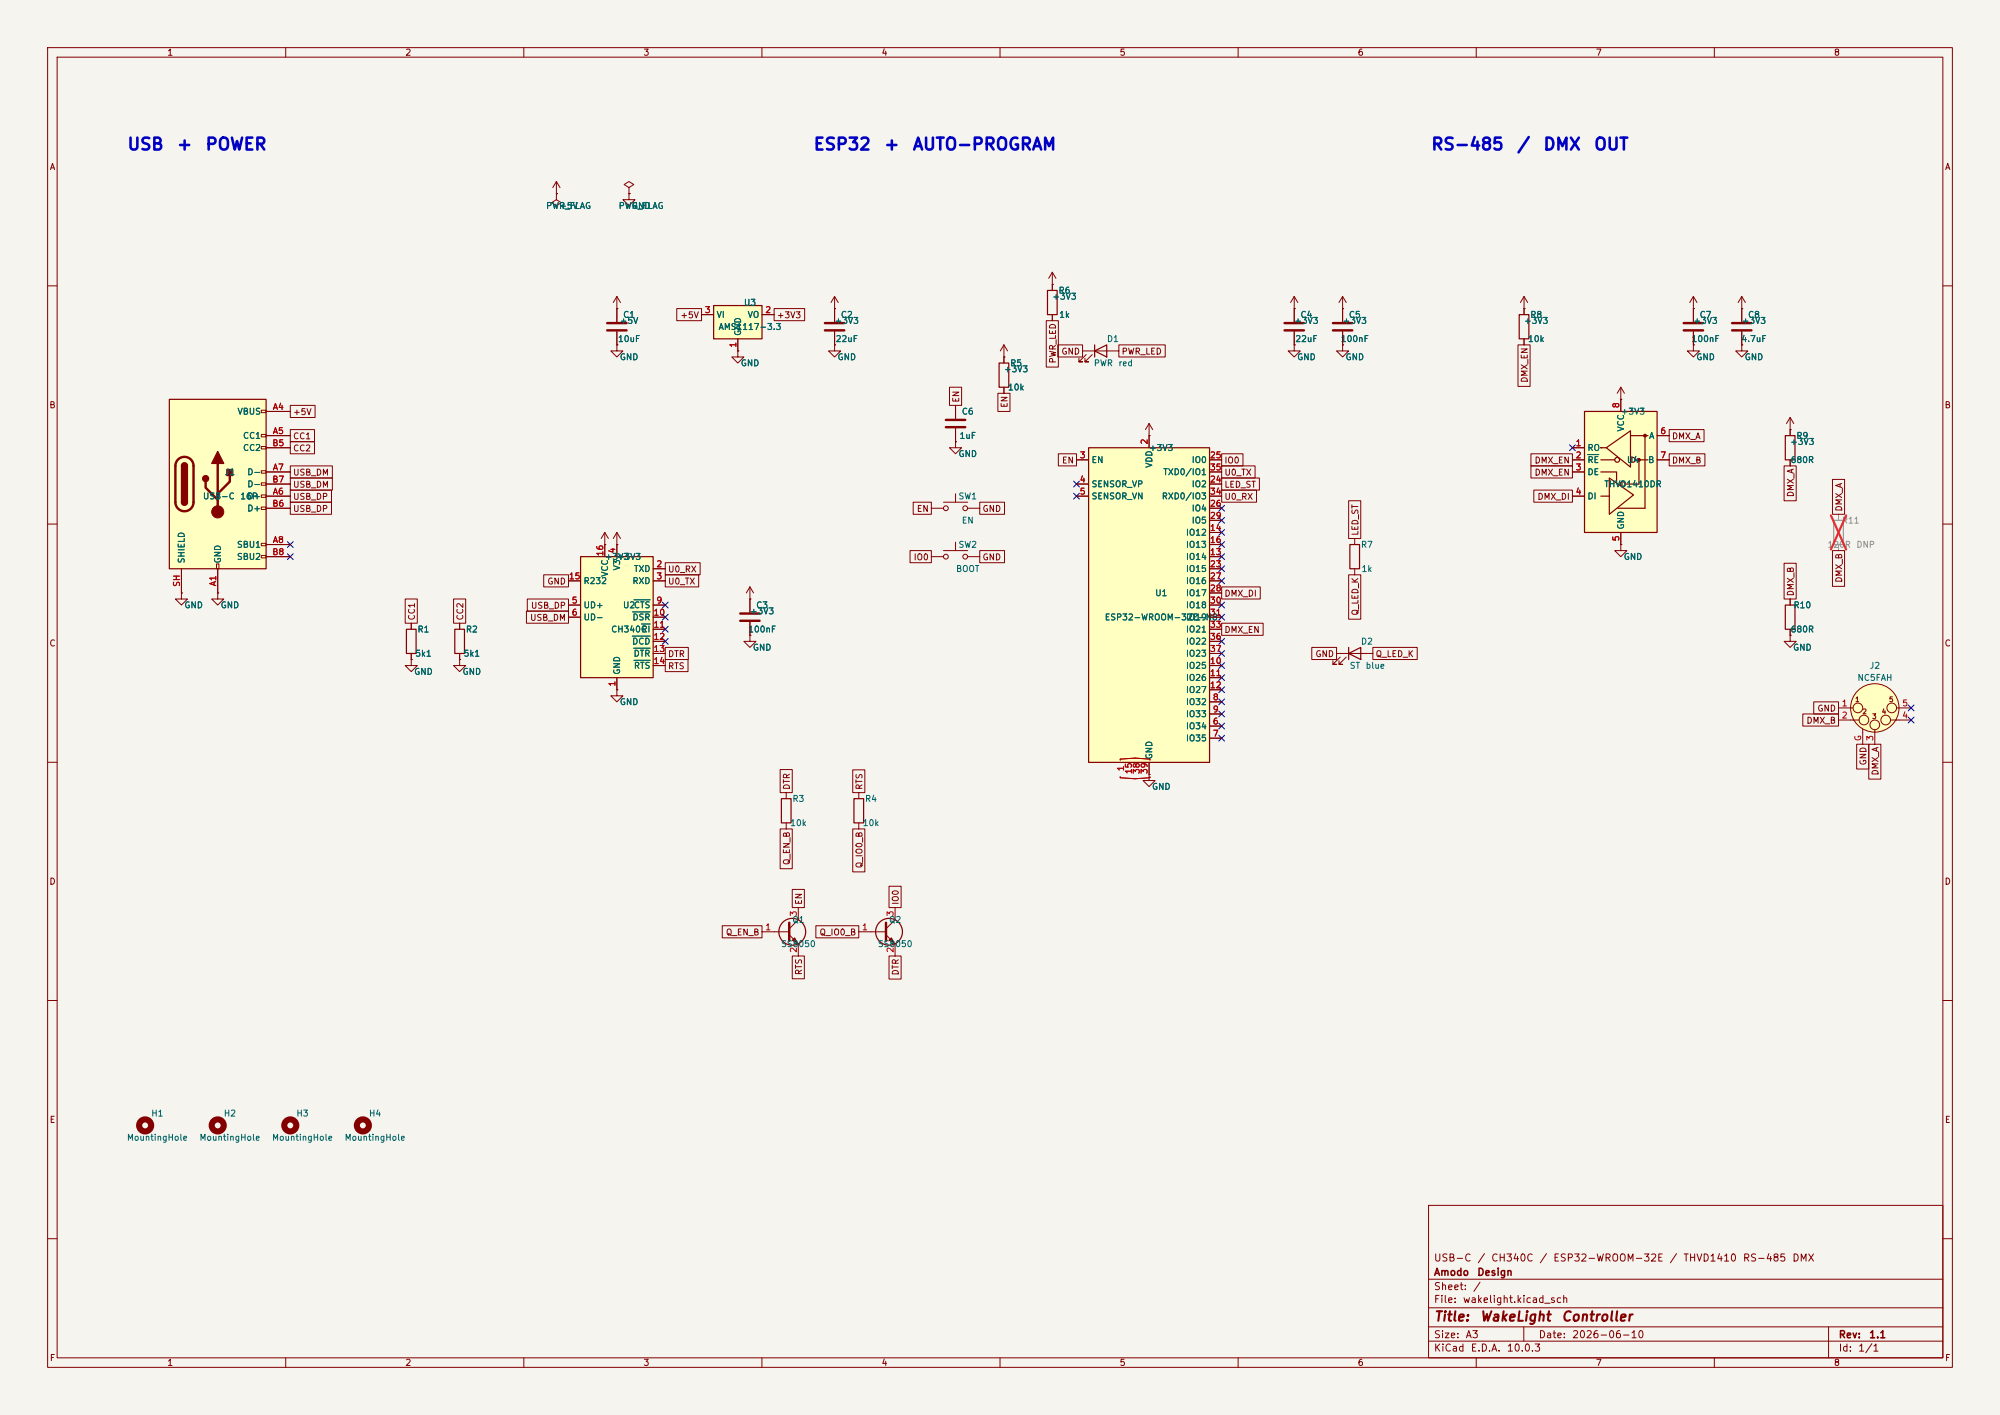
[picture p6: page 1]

4 UD+ 5 UD- 6 CTS 9 DSR 10 RI 11 DCD 12 DTR 13 RTS 14 R232 15 VCC 16 GND +3V3 GND +3V3 C2

4 UD+ 5 UD- 6 CTS 9 DSR 10 RI 11 DCD 12 DTR 13 RTS 14 R232 15 VCC 16 U2 CH340C

USB-C / CH340C / ESP32-WROOM-32E / THVD1410 RS-485 DMX
Amodo Design
Sheet: /
File: wakelight.kicad_sch
Title: WakeLight Controller

Size: A3 | Rev: 1.1 | F Date: 2026-06-10
KiCad E.D.A. 10.0.3 | Id: 1/1

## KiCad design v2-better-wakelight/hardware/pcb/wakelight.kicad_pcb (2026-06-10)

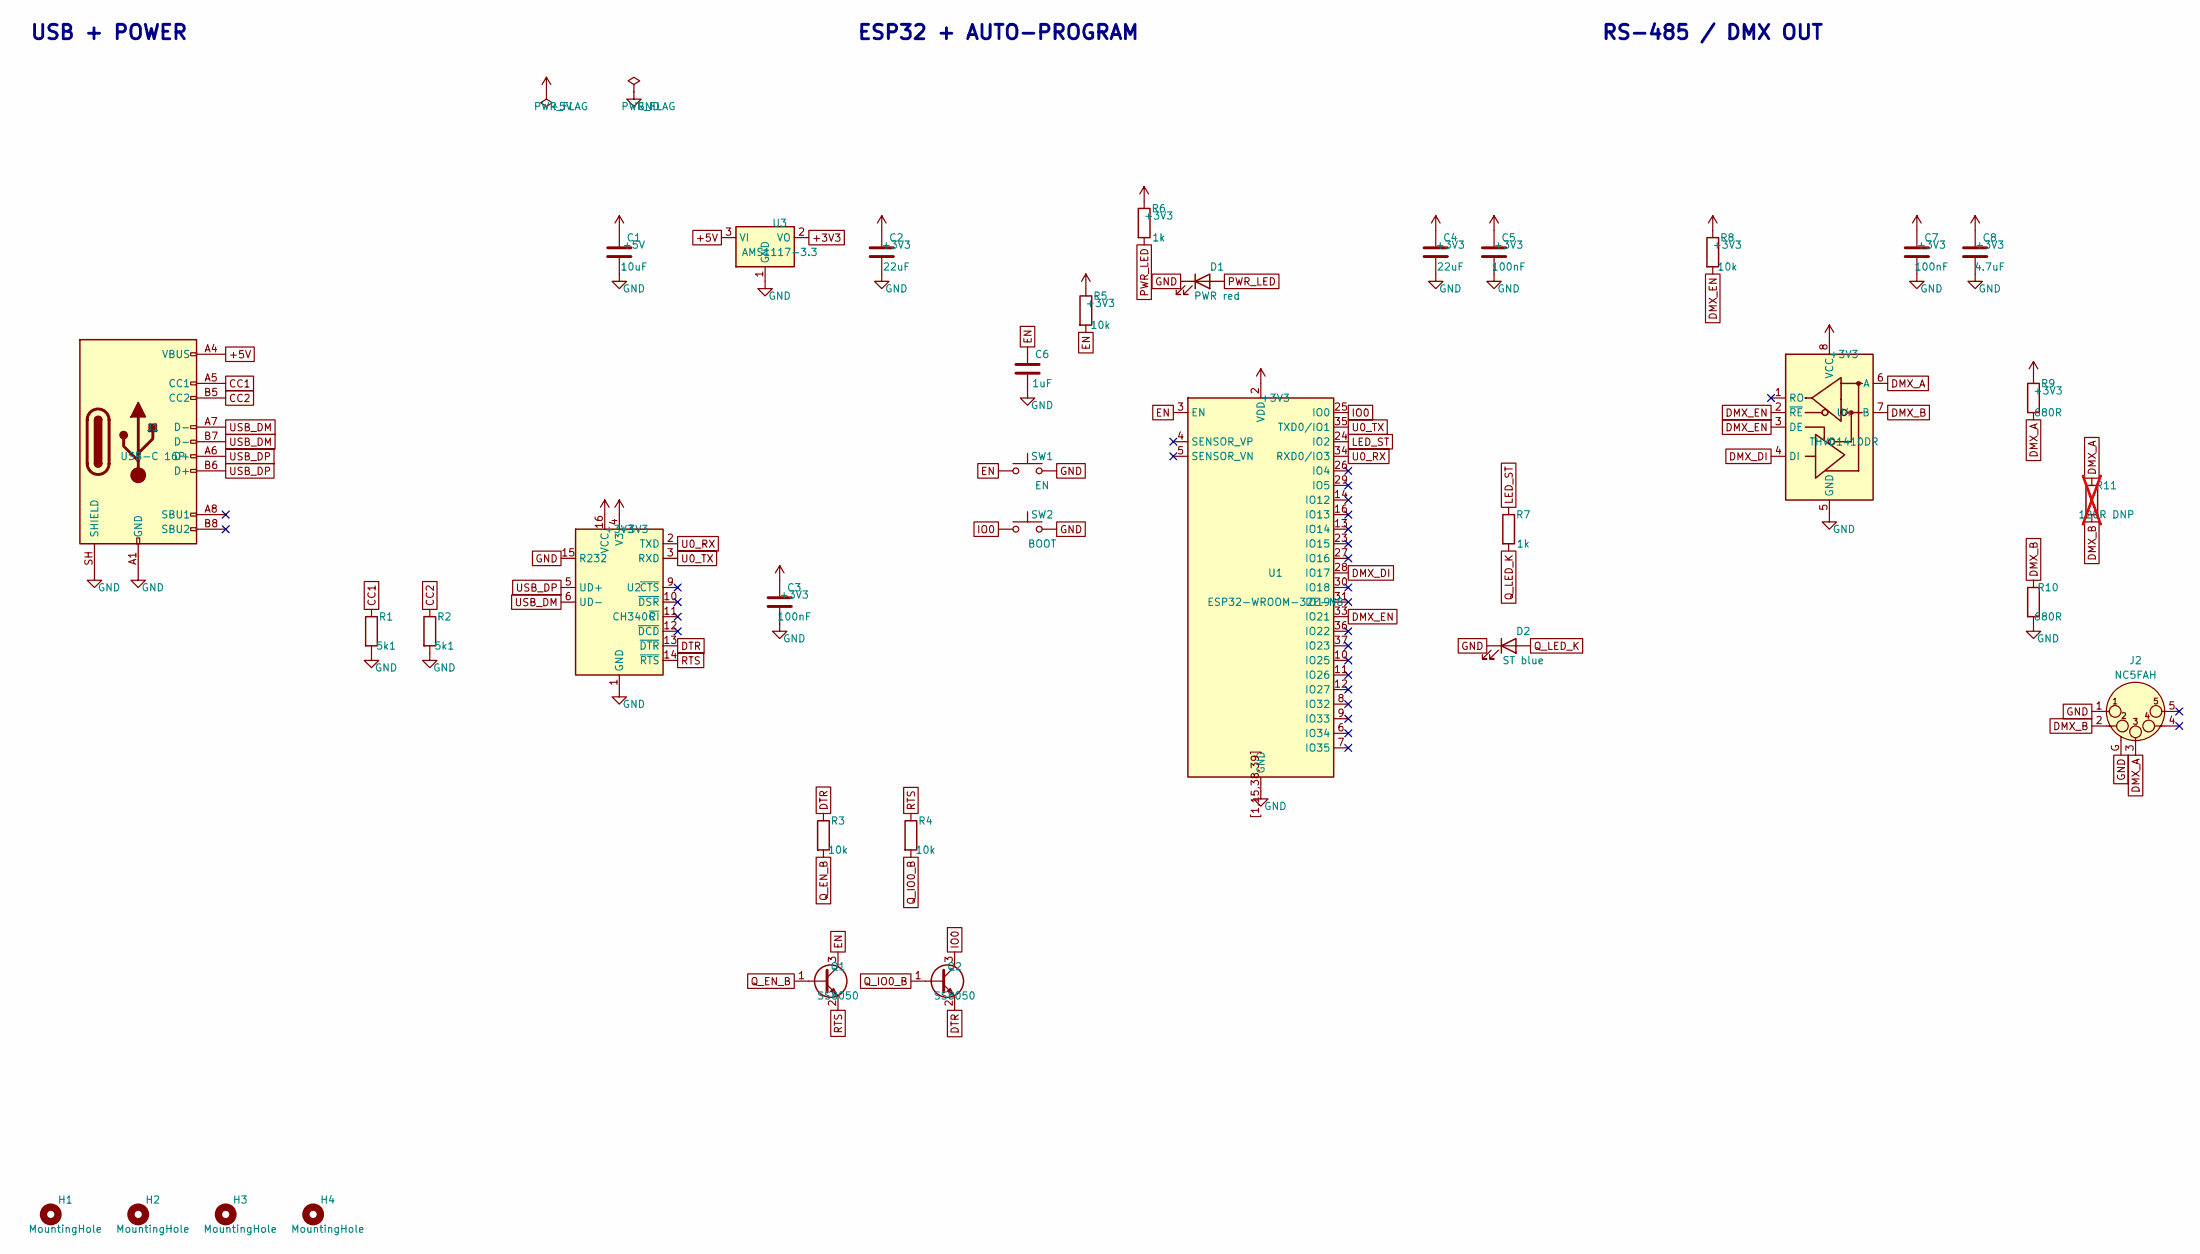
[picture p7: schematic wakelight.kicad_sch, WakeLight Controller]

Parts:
C1: 10uF; C_0805_2012Metric
C2, C4: 22uF; C_0805_2012Metric
C3, C5, C7: 100nF; C_0603_1608Metric
C6: 1uF; C_0603_1608Metric
C8: 4.7uF; C_0805_2012Metric
D1: PWR red; LED_0603_1608Metric
D2: ST blue; LED_0603_1608Metric
H1, H2, H3, H4: MountingHole; MountingHole_3.2mm_M3
J1: USB-C 16P; USB_C_Receptacle_HRO_TYPE-C-31-M-12
J2: NC5FAH; Jack_XLR_Neutrik_NC5FAH_Horizontal
Q1, Q2: SS8050; SOT-23
R1, R2: 5k1; R_0603_1608Metric
R3, R4, R5, R8: 10k; R_0603_1608Metric
R6, R7: 1k; R_0603_1608Metric
R9, R10: 680R; R_0603_1608Metric
R11: 120R DNP; R_0603_1608Metric; not fitted
SW1: EN; SW_SPST_TL3342
SW2: BOOT; SW_SPST_TL3342
U1: ESP32-WROOM-32E-N8; ESP32-WROOM-32E
U2: CH340C; SOIC-16_3.9x9.9mm_P1.27mm
U3: AMS1117-3.3; SOT-223-3_TabPin2
U4: THVD1410DR; SOIC-8_3.9x4.9mm_P1.27mm

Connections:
+3V3: C2.1, C3.1, C4.1, C5.1, C7.1, C8.1, R5.1, R6.1, R8.1, R9.1, U1.2 (VDD), U2.4 (V3), U2.16 (VCC), U3.2 (VO), U4.8 (VCC)
+5V: C1.1, J1.A4 (VBUS), J1.A9 (VBUS), J1.B4 (VBUS), J1.B9 (VBUS), U3.3 (VI)
CC1: J1.A5 (CC1), R1.1
CC2: J1.B5 (CC2), R2.1
DMX_A: J2.3, R9.2, R11.1, U4.6 (A)
DMX_B: J2.2, R10.1, R11.2, U4.7 (B)
DMX_DI: U1.28 (IO17), U4.4 (DI)
DMX_EN: R8.2, U1.33 (IO21), U4.2 (~RE), U4.3 (DE)
DTR: Q2.2 (E), R3.1, U2.13 (~DTR)
EN: C6.1, Q1.3 (C), R5.2, SW1.1, U1.3 (EN)
GND: C1.2, C2.2, C3.2, C4.2, C5.2, C6.2, C7.2, C8.2, D1.1 (K), D2.1 (K), J1.A1 (GND), J1.A12 (GND), J1.B1 (GND), J1.B12 (GND), J1.SH (SHIELD), J2.1, J2.G, R1.2, R2.2, R10.2, SW1.2, SW2.2, U1.1, U1.15, U1.38, U1.39, U1.[1,15,38,39] (GND), U2.1 (GND), U2.15 (R232), U3.1 (GND), U4.5 (GND)
IO0: Q2.3 (C), SW2.1, U1.25 (IO0)
LED_ST: R7.1, U1.24 (IO2)
PWR_LED: D1.2 (A), R6.2
Q_EN_B: Q1.1 (B), R3.2
Q_IO0_B: Q2.1 (B), R4.2
Q_LED_K: D2.2 (A), R7.2
RTS: Q1.2 (E), R4.1, U2.14 (~RTS)
U0_RX: U1.34 (RXD0/IO3), U2.2 (TXD)
U0_TX: U1.35 (TXD0/IO1), U2.3 (RXD)
USB_DM: J1.A7 (D-), J1.B7 (D-), U2.6 (UD-)
USB_DP: J1.A6 (D+), J1.B6 (D+), U2.5 (UD+)

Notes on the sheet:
USB + POWER
ESP32 + AUTO-PROGRAM
RS-485 / DMX OUT

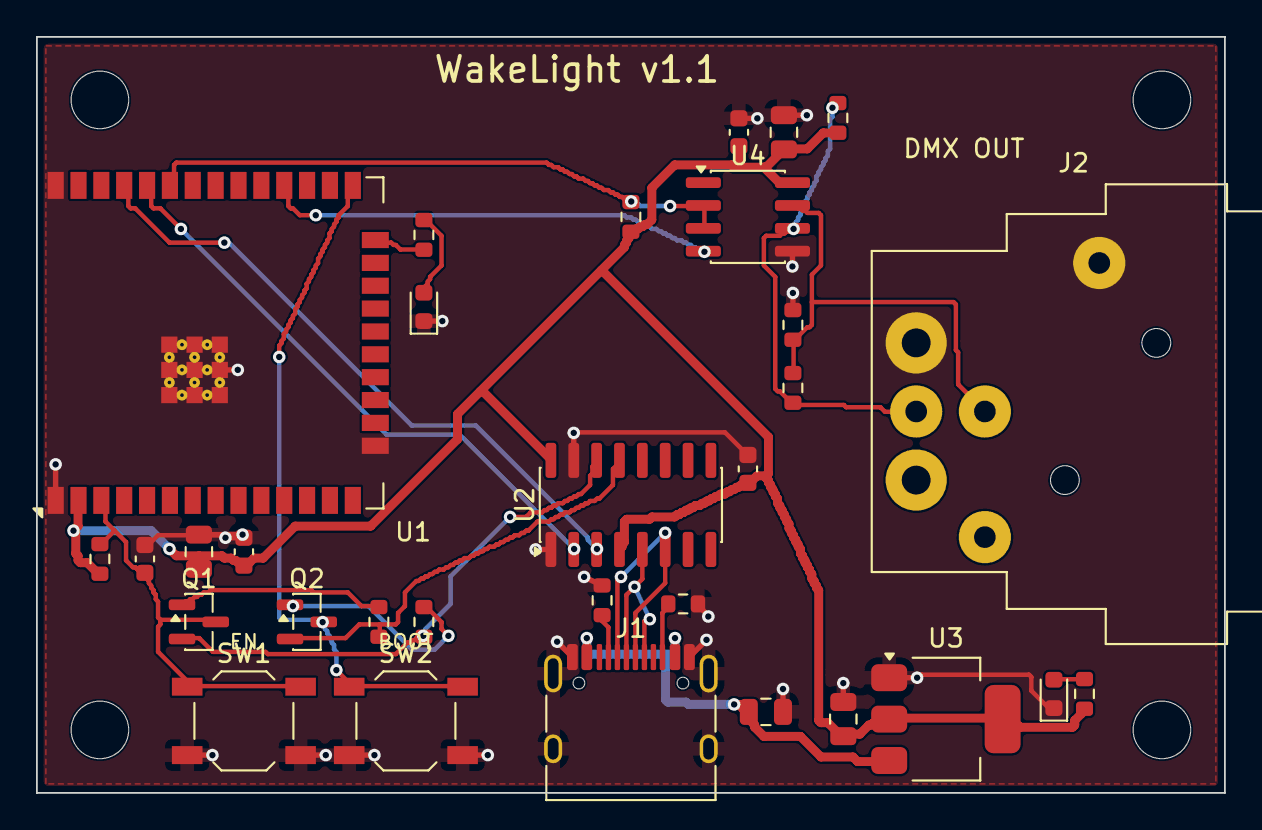
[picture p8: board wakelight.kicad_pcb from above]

Board: 2 copper layers, 66.0 x 42.0 mm, 35 parts (0 on the bottom side), 22 nets.

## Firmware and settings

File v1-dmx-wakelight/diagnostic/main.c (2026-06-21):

// DMX bus diagnostic firmware.
// Use when bringing up a new fixture or a flaky RS485 link.
// Build: `pio run -e diagnostic -t upload`
//
// Streams a 2s ON / 2s OFF blink on a Neewer PL60C at DMX address 1
// (adjust FIXTURE_ADDR for other fixtures), and logs per-second TX
// counters so you can tell whether the ESP side is sending cleanly:
//
//   tx: sent=34 zero=0 wait_ok=34 wait_timeout=0 enabled=1 last_n=513
//
// Expected healthy stream at 33 Hz: sent=~34, zero=0, wait_timeout=0.
// If sent=34 and wait_timeout=0 but the fixture is intermittent,
// the problem is physical: A/B polarity, termination, or grounding.

#include "esp_dmx.h"
#include "esp_log.h"
#include "esp_timer.h"
#include "freertos/FreeRTOS.h"
#include "freertos/task.h"

#define TX_PIN 17
#define RX_PIN 16
#define EN_PIN 4

#define FIXTURE_ADDR 1

static const char *TAG = "diagnostic";
static const dmx_port_t kDmxPort = DMX_NUM_1;
static uint8_t g_dmx[DMX_PACKET_SIZE];

static void apply(uint8_t brightness) {
  uint8_t *f = &g_dmx[FIXTURE_ADDR];
  f[0] = 0;
  f[1] = brightness;
  f[2] = 255;
  f[3] = 128;
  dmx_write(kDmxPort, g_dmx, DMX_PACKET_SIZE);
}

void app_main(void) {
  ESP_LOGI(TAG, "=== DMX diagnostic @ addr %d ===", FIXTURE_ADDR);

  dmx_config_t config = DMX_CONFIG_DEFAULT;
  if (!dmx_driver_install(kDmxPort, &config, NULL, 0)) {
    ESP_LOGE(TAG, "driver install failed");
    return;
  }
  dmx_set_pin(kDmxPort, TX_PIN, RX_PIN, EN_PIN);
  ESP_LOGI(TAG, "driver up, enabled=%d", dmx_driver_is_enabled(kDmxPort));

  const TickType_t period = pdMS_TO_TICKS(30);
  const int64_t blink_us = 2000000;
  int64_t last_toggle = esp_timer_get_time();
  int64_t last_stats = last_toggle;
  bool on = true;
  int cycle = 0;

  uint32_t sends_ok = 0, sends_zero = 0, waits_ok = 0, waits_timeout = 0;

  apply(255);
  ESP_LOGI(TAG, "#0 ON");

  TickType_t tick = xTaskGetTickCount();
  while (1) {
    int64_t now = esp_timer_get_time();

    if (now - last_toggle >= blink_us) {
      on = !on;
      apply(on ? 255 : 0);
      last_toggle += blink_us;
      if (on) cycle++;
      ESP_LOGI(TAG, "#%d %s", cycle, on ? "ON" : "OFF");
    }

    size_t n = dmx_send_num(kDmxPort, DMX_PACKET_SIZE);
    if (n > 0) sends_ok++; else sends_zero++;
    bool ok = dmx_wait_sent(kDmxPort, DMX_TIMEOUT_TICK);
    if (ok) waits_ok++; else waits_timeout++;

    if (now - last_stats >= 1000000) {
      ESP_LOGI(TAG, "tx: sent=%" PRIu32 " zero=%" PRIu32
                    " wait_ok=%" PRIu32 " wait_timeout=%" PRIu32
                    " enabled=%d last_n=%u",
               sends_ok, sends_zero, waits_ok, waits_timeout,
               dmx_driver_is_enabled(kDmxPort), (unsigned)n);
      sends_ok = sends_zero = waits_ok = waits_timeout = 0;
      last_stats = now;
    }

    vTaskDelayUntil(&tick, period);
  }
}

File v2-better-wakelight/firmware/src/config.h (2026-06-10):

#pragma once
#include <Arduino.h>

// ---------------------------------------------------------------------------
// Persistent configuration (NVS-backed) for the WakeLight controller.
// ---------------------------------------------------------------------------

// Fixture DMX profile. The Neewer PL60C has a single personality where the
// base channel n SELECTS the operating mode (0-31 CCT, 32-63 HSI, ...), n+1 is
// always brightness, and the meaning of n+2.. depends on the mode — per the
// official Neewer "PL60C DMX Channel Table" (see docs/dmx-profile.md).
enum FixtureMode : uint8_t {
  MODE_PL60C = 0,     // native: n=mode select, n+1=dim, CCT or HSI sub-map
  MODE_GENERIC_CCT,   // simple fixtures: n=dimmer, n+1=CCT
  MODE_CUSTOM,        // user-defined channel offsets below
};

struct AlarmDay {
  bool     enabled = false;
  uint8_t  hour    = 7;      // alarm time = moment of full brightness
  uint8_t  minute  = 0;
};

struct Config {
  // --- fixture ---
  uint16_t dmxAddress   = 1;          // base address set on the lamp
  uint8_t  fixtureMode  = MODE_PL60C;
  // custom-mode channel offsets (0 = ch at base address). 255 = not present.
  uint8_t  chDimmer     = 0;
  uint8_t  chCct        = 1;
  uint8_t  chHue        = 255;
  uint8_t  chSat        = 255;
  // CCT range of the fixture in Kelvin, for mapping K -> DMX value.
  // PL60C: 2500K-10000K linear across 0-255 (official channel table).
  uint16_t cctMinK      = 2500;
  uint16_t cctMaxK      = 10000;

  // --- sunrise ---
  AlarmDay alarms[7];                  // 0 = Sunday ... 6 = Saturday (tm_wday)
  uint16_t rampMinutes   = 25;         // sunrise duration, ends at alarm time
  uint8_t  finalLevel    = 100;        // % brightness at alarm time
  uint16_t finalCctK     = 5600;       // colour temp at alarm time
  uint16_t startCctK     = 2500;       // colour temp at the start of the ramp
  uint16_t holdMinutes   = 60;         // stay on this long after alarm, then off

  // --- system ---
  char     tz[48]        = "GMT0BST,M3.5.0/1,M10.5.0";  // Europe/London
  char     ntpServer[48] = "pool.ntp.org";
  char     hostname[32]  = "wakelight";

  void load();
  void save();
  void reset();
};

extern Config cfg;

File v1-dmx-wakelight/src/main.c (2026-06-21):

#include "device_id.h"
#include "dismiss.h"
#include "dmx_out.h"
#include "http_ui.h"
#include "override.h"
#include "schedule.h"
#include "wifi_sntp.h"

#define OVERRIDE_ON_BYTE 255  // full brightness
#define OVERRIDE_ON_CCT 4000

#include "esp_log.h"
#include "freertos/FreeRTOS.h"
#include "freertos/task.h"

#include <time.h>

static const char *TAG = "wakelight";

static void ramp_task(void *arg) {
  (void)arg;
  const TickType_t period = pdMS_TO_TICKS(1000);
  TickType_t tick = xTaskGetTickCount();
  while (1) {
    time_t now = time(NULL);
    struct tm lt;
    localtime_r(&now, &lt);
    uint32_t sod = (uint32_t)lt.tm_hour * 3600 + (uint32_t)lt.tm_min * 60 + (uint32_t)lt.tm_sec;

    override_mode_t ov = override_get();
    if (ov == OVERRIDE_ON) {
      dmx_out_set(OVERRIDE_ON_BYTE, OVERRIDE_ON_CCT, 128);
    } else if (ov == OVERRIDE_OFF) {
      dmx_out_set(0, 2700, 128);
    } else if (ov == OVERRIDE_MANUAL) {
      uint8_t mpct = 0;
      uint16_t mk = 2700;
      uint8_t mgm = 128;
      override_get_manual(&mpct, &mk, &mgm);
      uint8_t mb = (mpct >= 100) ? 255 : (uint8_t)((uint32_t)mpct * 255 / 100);
      dmx_out_set(mb, mk, mgm);
    } else {
      // AUTO: follow schedule unless the user dismissed for today.
      if (dismiss_is_active()) {
        dmx_out_set(0, 2700, 128);
      } else {
        schedule_t s;
        schedule_get(&s);
        eval_t e;
        bool active = schedule_eval(&s, sod, &e);
        if (!active) {
          dmx_out_set(0, 2700, 128);
        } else if (e.is_fx) {
          dmx_out_set_fx(e.brightness_byte, e.fx_effect_byte, e.fx_params);
        } else {
          dmx_out_set(e.brightness_byte, e.cct_k, 128);
        }
      }
    }
    vTaskDelayUntil(&tick, period);
  }
}

void app_main(void) {
  ESP_LOGI(TAG, "wakelight booting");

  dmx_out_start();
  dmx_out_set(0, 2700, 128);

  schedule_t s;
  schedule_load(&s);
  dismiss_init();
  device_id_init();

  if (!wifi_sntp_start()) {
    ESP_LOGE(TAG, "wifi failed; continuing without network");
  } else {
    http_ui_start();
  }

  xTaskCreate(ramp_task, "ramp", 4096, NULL, 4, NULL);
}

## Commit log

2026-06-10 WakeLight: ESP32 DMX sunrise controller for Neewer PL60C
    Complete MVP: firmware (esp_dmx + web portal + scheduler), DRC-clean
    custom PCB with JLCPCB fab/assembly files, ERC-clean schematic,
    module-build guide, and UK ordering pack.
    [enclosure.scad, jlcpcb_bom.csv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]
2026-06-10 Fix U1 rotation in JLC CPL (library zero mismatch, verified in placement preview)
    [jlcpcb_cpl.csv]
2026-06-10 CPL: fix U2/U4 SOIC rotation offsets and J2 centre position for JLC
    [jlcpcb_cpl.csv]
2026-06-10 WakeLight v1.1: PCB-mount Neutrik NC5FAH 5-pin XLR DMX output
    Board widened to 66x42mm, XLR footprint verified against the official
    Neutrik drilling plan, regulator corner re-placed, DRC clean (0 errors,
    0 unconnected). Schematic updated (ERC clean), v1.0 terminal-variant fab
    files archived, docs and sourcing updated.
    [enclosure.scad, jlcpcb_bom.csv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]
2026-06-10 Enclosure v1.1: round XLR panel aperture on true mating axis, deeper cavity
    NC5FAH flange is 25.3 sq centred 9mm above the PCB; wall now acts as the
    front panel with a 23mm round aperture (Neutrik min 22), cavity deepened
    to clear the flange, vents moved off the connector body.
    [enclosure.scad]
2026-06-10 Add software SDF preview renderer for the enclosure (no OpenSCAD/GPU needed)
2026-06-10 Add STL exporter (SDF marching cubes) for the enclosure
2026-06-16 Add RS485/DMX output self-check (bench bring-up)
    Dedicated env:selfcheck links the real dmx_engine.cpp + config.cpp against
    diag/selfcheck.cpp (no Wi-Fi/portal) and reports over serial:
    - esp_dmx driver install + pin assignment
    - DMX frame rate from the live packet counter (~21 Hz, = dmx_wait_sent
    ~23 ms/frame + 25 ms task delay; valid DMX512, not the 40 Hz the bare
    delay implies)
    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
2026-06-16 Track enclosure STL meshes (box + lid) for GitHub download/preview
    The marching-cubes export was gitignored as a generated artifact. Add the
    two enclosure deliverables (enclosure_box.stl, enclosure_lid.stl) to the
    repo so they download directly and render in GitHub's 3D viewer; keep the
    blanket *.stl ignore for any other regenerated meshes. Regenerate with
    hardware/pcb/export_stl.py.
2026-06-19 Fix DMX enable line: hold GPIO21 HIGH instead of letting esp_dmx key RTS
    This is a transmit-only board (RO unconnected), so the RS-485 transceiver
    must always be in drive mode. Handing the DE//RE enable pin to esp_dmx as
    its UART-RTS line left the driver un-asserted during TX on this wiring: the
    PL60C saw a valid stream for a moment at boot then lost it ("opened DMX then
    vanished"), and the bench self-check measured GPIO21 HIGH on 0/54638 samples.
    dmx_engine.cpp now calls dmx_set_pin(..., rts=-1) and drives GPIO21 HIGH as a
    plain output in begin(), so the driver is enabled continuously. Confirmed on
    the bench via diag/enable_probe.cpp (env:enprobe) — lamp blinks as commanded.
    Co-Authored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
    [dmx_engine.cpp, enable_probe.cpp]
2026-06-19 Add output-stage wiring diagram to README
    SVG schematic of the DMX output stage (ESP32 -> THVD1410 -> female 5-pin XLR),
    matching the actual board netlist: transmit-only (RO n/c), DE+/RE tied to
    GPIO21, 680R fail-safe bias, 120R DNP termination, +3V3 from on-board AMS1117.
2026-06-19 Add full-board schematic diagram to README
    Complete board schematic (docs/schematic-diagram.svg) covering every PCB part:
    USB-C (J1) + CC resistors, AMS1117 LDO (U3) + bulk caps, CH340C (U2) with the
    SS8050 DTR/RTS auto-program circuit (Q1/Q2/R3/R4), ESP32 (U1) with EN/boot
    network (R5/C6/SW1/SW2), THVD1410 (U4) RS-485 output with fail-safe bias and
    DNP termination, the female XLR (J2), indicator LEDs (D1/D2), and the +3V3
    decoupling bank. Net-name tags connect across functional blocks.
    Keeps the focused output-stage wiring diagram as a "detail" view under it.
2026-06-21 Restructure repo into v1 and v2 wakelight subprojects
    Both are independent ESP32 DMX sunrise controllers for the Neewer PL60C,
    each self-contained in its own folder:
    - v2-better-wakelight/: existing content (custom PCB + firmware + portal),
    moved from the repo root unchanged.
    - v1-dmx-wakelight/: the earlier ESP-IDF/PlatformIO waypoint-ramp build,
    imported as a sibling subproject.
    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
    [enclosure.scad, jlcpcb_bom.csv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]
2026-06-21 v2 README: clearer file map, JLCPCB order links, flashing guide, firmware warning
    - "Where everything is" table pointing to exact files in v2-better-wakelight/
    - JLCPCB section with direct links to Gerbers, BOM, and CPL (pick-and-place)
    - Flashing guide: run Claude Code in firmware/, plus manual PlatformIO steps
    - Prominent warning that this is rough bring-up firmware; prettier one ~July 2026
    - No embedded schematic (linked under docs/ instead)
2026-06-21 Show custom PCB (XLR variant) renders in root and v2 READMEs
    Add top + bottom board renders of the XLR-connector custom PCB to the v2
    README and to the v2 section of the root README.
2026-06-21 v2: trim repo to the final XLR custom-PCB build only
    Remove content that isn't the final XLR board so there's no confusion:
    - orders/ORDER_THIS_WEEK.md (dated to-do list)
    - hardware/module-build/ (the no-PCB breadboard/module alternative)
    - hardware/pcb/v1.0-terminal/ (superseded screw-terminal board variant)
    - hardware/pcb/xlrtest.* (scratch KiCad project)
    - enclosure STL box (enclosure_box.stl, enclosure_lid.stl, preview) — kept
    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
    [jlcpcb_bom.csv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]
2026-06-21 v2: remove the enclosure entirely
    Drop the remaining enclosure source/tooling (enclosure.scad, export_stl.py,
    render_enclosure.py) and the enclosure-specific .gitignore rules. The repo is
    now purely the final XLR custom-PCB build (board, gerbers, BOM/CPL, firmware,
    docs).
    [enclosure.scad]
